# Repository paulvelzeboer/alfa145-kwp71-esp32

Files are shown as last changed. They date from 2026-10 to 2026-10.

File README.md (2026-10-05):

# Alfa 145 QV KWP71 reader: ESP32 CYD + ISO 9141 Click

Reads a **Bosch Motronic M2.10.4** (Alfa Romeo 145 QV, part 0261204478) over the K-line with the old Bosch **KWP71** protocol. It runs on an **ESP32-2432S028 "Cheap Yellow Display"** with a **MikroE ISO 9141 Click**, and shows a live dashboard on the CYD's screen: an rpm gauge, four values (battery, coolant, air temp, air quantity), the ECU ID numbers, and a boot splash with the car badge.

**Status (22 Sep 2026):** the full handshake and live values work on the real ECU (bench, engine off). The ESP32 reads 12.27 V, 18 °C and 0 rpm, plus the ID blocks: HW 0261204478, SW 1037357941, PN 46525168. The smoother dashboard (rpm polled ~3–4×/s, display on the second core) compiles but hasn't been tested on the ECU yet.

The full bring-up story, wiring, protocol findings and troubleshooting are in **[docs/kwp71-m2104-bringup.md](docs/kwp71-m2104-bringup.md)**.

## Repository layout

| Path | What |
| --- | --- |
| `firmware/kwp71_m2104_esp32/` | Main sketch: KWP71 handshake, polling, TFT dashboard, demo mode |
| `firmware/kline_loopback_test/` | Wiring test: sends bytes on TX (GPIO27) and checks they come back on RX (GPIO22) |
| `tools/kwp71_m2_10_4.py` | PC tool: KWP71 over a KKL / VAG-COM 409.1 cable (`--probe` for wakeup + sync only) |
| `tools/m2104_sim.py` | M2.10.4 simulator: the PC + KKL cable plays the ECU for desk testing |
| `tools/check_wakeup.py` | Decodes the 5-baud 0x10 wakeup from a sigrok CSV capture |
| `tools/make_case.py` | Generates the case (STL + 3MF) from the dimensions at the top of the file |
| `tools/trace_badge.py` | Traces a badge image into outlines for the lid |
| `tools/make_logo_header.py` | Converts a logo image into display data for the sketch |
| `docs/kwp71-m2104-bringup.md` | Documentation: bring-up plan, results, dashboard, troubleshooting |
| `captures/` | Logic analyzer captures (the existing ones show no K-line activity; see the doc, P0) |
| `hardware/` | Printable case for the CYD + Click: STL files plus `case_lid.3mf` for multi-colour printing, see [hardware/README.md](hardware/README.md) |
| `archive/` | Older sketch version and an old KKL tool log, for reference only |

## Hardware and wiring

| From | To | Note |
| --- | --- | --- |
| CYD CN1 IO27 (K_TX) | Click mikroBUS pin marked **RX** | the Click's pin names are from its own side, so TX/RX cross |
| Click mikroBUS pin marked **TX** | CYD CN1 IO22 (K_RX) | |
| CYD CN1 3.3V / GND | Click +3.3V / GND | Click jumper **JP1 = 3V3** (5V would put 5 V on GPIO22) |
| Click K screw | ECU diag connector **pin 3 (K)** | 3-pin Fiat/Alfa connector: pin 1 not connected, pin 2 GND, pin 3 K |
| Click GND | ECU diag connector **pin 2 (GND)** and 12 V minus | shared ground is required |
| 12 V (1 A fuse) | Click VS terminal + ECU supply | |

Never connect the K-line or 12 V directly to the ESP32 or the logic analyzer. For probing the K-line, use a 47 kΩ / 15 kΩ divider (see the doc).

## Firmware

Needs the ESP32 Arduino core (tested with 3.3.11) and **TFT_eSPI** (2.5.43) set up for the CYD pins with `ST7789_DRIVER`. The sketch itself switches on the backlight, turns off colour inversion and sets BGR colour order; the stock setup gets all three wrong for this panel.

```sh
arduino-cli compile --upload -p /dev/cu.usbserial-XXXX \
  --fqbn esp32:esp32:esp32:UploadSpeed=115200 firmware/kwp71_m2104_esp32
arduino-cli monitor -p /dev/cu.usbserial-XXXX -c baudrate=115200
```

The CYD's CH340 USB chip drops out at the default 921600 baud, hence `UploadSpeed=115200`.

`#define DEMO_MODE 1` shows simulated values without an ECU. Set it to `0` for the car.

The Alfa badge on the boot splash and in the status bar comes from an image that isn't in this repository, since car maker logos are trademarks. To show it, put your own `logo.png` in the project root and run:

```sh
pip install pillow
python3 tools/make_logo_header.py logo.png
```

Without that header the sketch still builds: the splash is then text-only.

## PC tools

```sh
pip install pyserial
python3 tools/kwp71_m2_10_4.py --port /dev/cu.usbserial-AH01164M --probe   # KKL: wakeup + sync only
python3 tools/m2104_sim.py --port /dev/cu.usbserial-AH01164M              # KKL plays the ECU
python3 tools/check_wakeup.py capture.csv --channel K_LINE --address 0x10 # check a wakeup capture
```

Only one tester may be on the K-line at a time: unplug the KKL when the Click is connected, and the other way round (the simulator setup excepted).

## Protocol facts for this ECU (measured)

| Item | Value |
| --- | --- |
| Wakeup | address 0x10 at 5 baud, K-line idle high ≥ 2 s before the start bit |
| Sync | ECU sends 0x55 about 180–190 ms after the stop bit, then `32 86 04 15 26` at 4800 baud |
| Keyword reply | complement of byte #1: 0x86 → **0x79** |
| Blocks | `LEN CTR TYPE DATA… 03`. **LEN counts the 0x03.** Every byte is echoed inverted, except the 0x03 |
| Quirk | the ECU always sends the LEN byte of its first block twice; echo the repeat, don't store it |
| Echo timing | 10–30 ms before each echo works; 0 ms is rejected |
| ID blocks | type F6, ASCII reversed: 0261204478 / 1037357941 / 46525168 |
| Battery | `01 01 00 36` → FE + 1 byte, × 0.1319 V (calibrated at 12.4 V) |
| Coolant | `08 03` → FB + 2 bytes, polynomial on the low byte |
| RPM | `01 02 00 3B` → FE + 2 bytes; formula **not verified** with a running engine |

## 3D-printed case

`hardware/` holds a two-part case: a shell with posts for the CYD and a slide-in holder for the Click, and a lid with a window for the display and the quadrifoglio inlaid in its top layers. Regenerate after changing any dimension:

```sh
python3 tools/make_case.py
```

Print `case_clickfit.stl` and `case_fitcheck.stl` first; they check the fit in minutes. Details and print settings are in [hardware/README.md](hardware/README.md).

## Open items

- RPM formula and a second battery calibration point, with the engine running.
- The first request after the handshake always gets a NAK. It's harmless, but a short pause might avoid it.
- Air temperature and air quantity have display cells but aren't requested from the ECU yet (air temp is probably ADC channel 02; the air quantity address is unknown).
- The case is unprinted apart from the Click holder coupon. The terminal height under the Click (7.0 mm) and the pin height above it (8.0 mm) are estimates, and they set the case height.

## License

MIT, see [LICENSE](LICENSE).

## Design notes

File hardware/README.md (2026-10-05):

# Case for the CYD + ISO 9141 Click

Two-part printable case, generated by [`tools/make_case.py`](../tools/make_case.py):

| File | What | Size |
| --- | --- | --- |
| `case_fitcheck.stl` | Coupon with the CYD post pattern. **Print this first.** | 122 × 56 × 7.8 mm |
| `case_clickfit.stl` | Coupon with the Click holder, at the real board height. **Print this too.** | 37 × 39 × 13.9 mm |
| `case_bottom.stl` | Shell: floor, walls with openings, CYD posts, Click slide-in holder | 127.2 × 60.8 × 21.1 mm |
| `case_lid.3mf` | **Lid + badge as one object in three parts**, badge inlaid flush - open this for multi-colour printing | 127.2 × 60.8 × 8 mm |
| `case_lid.stl` | Lid: screen window and lip, **no badge** - the base part if you prefer STLs | 127.2 × 60.8 × 8 mm |
| `case_lid_badge_triangle.stl` | Badge triangle, inlaid in the lid's top 0.6 mm | 44 × 39.8 × 0.6 mm |
| `case_lid_badge_clover.stl` | Clover, inlaid in the same 0.6 mm | 25.3 × 25.3 × 0.6 mm |
| `case_lid_embossed.stl` | Lid with the badge raised 1.4 mm, for printing in one colour | 127.2 × 60.8 × 9.4 mm |

Assembled height is about 23.1 mm.

> **The CYD outline and hole pattern come from the manufacturer drawing** ([mischianti.org](https://mischianti.org/wp-content/uploads/2025/04/ESP32-2432S028-Cheap-Yellow-Display-Dimensions.jpg.webp)): board 86.0 x 50.0 mm, hole centres 4.0 mm in from each edge, so the pattern is **78 x 42 mm**, corners R1.6.
>
> **Everything else is still nominal** and not measured: the mounting hole diameter (assumed 3.0 mm, not dimensioned in the drawing), the position of the active display area on the board, the Click's outline and the height of its screw terminals. Print the fit-check coupon first; nobody has printed any of this yet.

## Layout

```text
   top view of the open shell
   +---------------------------------------------+
   |  o                           o  |           |
   |        [   CYD board     ]      |  [Click]  ]==  screw terminals
   |  o                           o  |           |      (opening in the wall)
   +---------------------------------[wires]-----+
```

- **The Click's pins set the height.** The lid is closed over the Click, so the pins (`CLICK_PIN_H`, 8 mm, **measure this** - more if plugs stay on with the lid shut) are the tallest thing inside: 19.1 mm of inner height.
- **The CYD posts are 11.5 mm tall**, derived, not fixed: the generator makes them exactly tall enough to bring the display to 2 mm under the lid, so the screen isn't sunk in a well. Change any height and the posts follow.
- **The lid is flat** at this height. If a change ever makes the Click taller than the display, the generator sinks the screen panel automatically instead.
- **The lid has no screws.** It drops in with a 6 mm lip, 0.3 mm clearance per side. If it's loose, raise `LID_CLEAR`; if it's tight, lower it.
- **Posts** are hollow for M3 self-tapping screws: 2.4 mm pilot for the CYD, 2.2 mm for the Click. The four CYD posts carry a **2.7 mm alignment pin, 1.8 mm tall**, that enters the board's mounting hole, so the board sits in place even without screws. If the pins don't enter, measure the hole and set `CYD_HOLE_DIA`; the pin is that minus `SPIGOT_CLEAR` (0.3 mm).
- **The Click slides into a holder, pins up** - its mounting holes aren't used. From [`iso_9141_click_v101.dxf`](../iso_9141_click_v101.dxf): outline 25.40 × 28.57 mm, two 8-pin headers 22.86 mm apart (1.27 mm from the long edges), pins running from 3.81 to 21.59 mm along the board.
  - **A pocket at the back edge** takes the last 3 mm of the board, where there are no pins. Nothing grips the long edges: a rail there would ride over the pin rows while sliding in.
  - **Two ledges** support the front corners from below, clear of the screw terminals in the middle. Their ramped snap nubs sit on top of the board and clear both pin columns.
  - **The board sits `CLICK_BOARD_Z` = 8.5 mm above the floor**: `CLICK_TERM_STACK` (7.0 mm of terminal under the board) plus 1.5 mm of air. **Measure the terminal height and correct `CLICK_TERM_STACK`** - it is the only number that sets the board height, and 7.0 is an estimate from the first fit print.
  - **Fitting:** wire the terminals, slide the back edge 3 mm into the pocket, then press the front down until it snaps over the nubs. Do any wiring to the pins before closing the lid: the lid covers the Click completely.
- **A quadrifoglio is embossed on the lid**, right of the screen window, **41 × 37 mm** in two levels: the rounded triangle stands 0.6 mm proud and the clover 1.4 mm, so the clover reads clearly against it.
  - **It is traced from an image**, so the shape is the real badge rather than my approximation of it:
    ```sh
    pip install pillow
    python3 tools/trace_badge.py clover.png
    ```
    That writes `tools/badge_data.py`, which `make_case.py` picks up automatically. Green pixels and the outline around them become the clover; the remaining grey becomes the triangle, filled solid.
  - **The image and the traced data are not in the repository** (car maker logos are trademarks): `clover.png` and `tools/badge_data.py` are in `.gitignore`. Without them the generator falls back to a clover drawn from curves, so the STLs still build.
  - `CLOVER = False` removes the badge; `CLOVER_H` and `CLOVER_TRI_H` set the two relief heights.
  - **Printing it in green:** the clover is the only thing above 3.0 mm from the lid's underside, so a filament change at that layer gives a green clover on a grey triangle.
- **One opening only:** the Click's terminal wires, in the front wall (x 95.1-117.1, 2.5-10.5 mm above the floor). Every other wall is solid. The K-line and 12 V wires go to the Click's screw terminals, so they leave through that opening. There is no USB cut-out; set `USB_OPENING = True` to get one back, and no opening behind the CYD where its micro-SD slot sits.

## Printing the badge in other colours (Bambu Studio + AMS)

**Open `case_lid.3mf`.** It holds one object made of three parts, already in
place: `lid`, `badge triangle` and `badge clover`. Right-click a part and pick
its filament, for example white for the triangle and green for the clover. The
file carries suggested colours (grey / white / green), which some slicers show
straight away.

**The badge is inlaid, not raised:** all three parts end flush at the lid
surface (2.0 mm), with the colours filling the top 0.6 mm, so the lid stays
flat and the badge is a colour change only. The parts deliberately overlap each
other and the lid; slicers give an overlap to the part listed last, which is
why the clover comes after the triangle. `BADGE_INLAY = False` in the generator
raises the badge instead, and `BADGE_INLAY_DEPTH` sets how deep the colours
reach.

If you would rather build it from STLs: open `case_lid.stl`, then right-click
the object, **Add part -> Load**, and pick `case_lid_badge_triangle.stl` and
`case_lid_badge_clover.stl`. Loading as a part keeps each file's coordinates,
so they land exactly on the lid.

The parts meet rather than overlap: the lid ends at 2.0 mm, the triangle runs 2.0-2.6 mm, the clover 2.6-3.4 mm, and the clover sits entirely within the triangle's footprint. For a single-colour print use `case_lid_embossed.stl` instead: there the badge stands 1.4 mm proud, so it is visible without a colour change. The inlaid badge would be invisible in one colour.

## Printing

- **Material:** PLA or PETG. PETG if it's going to sit in a car in the sun.
- **Layers:** 0.2 mm, 3 perimeters, 20% infill.
- **Orientation:** both parts flat on the bed as generated, no supports needed. The lid prints with the screen panel upwards.
- **Time:** the coupon is a few minutes; the shell is roughly 2–3 hours depending on the printer.

## Checking the fit, then adjusting

1. Print `case_fitcheck.stl` (CYD posts) and `case_clickfit.stl` (Click holder). The CYD should drop onto the pins without force, and the Click should slide into the rails and click past the nubs.
2. Measure anything that's off and change the numbers in the `PARAMETERS` block at the top of `tools/make_case.py`:
   - `CYD_W/D/T`, `CYD_HOLE_INSET_X/Y`, `CYD_HOLE_DIA` for the display board (outline and insets now match the drawing; only the hole diameter is a guess),
   - `CLICK_W/D/T` (from the DXF), `CLICK_TERM_STACK` and `CLICK_BOARD_Z` for the space under the board, `CLICK_RAIL_*`, `CLICK_LEDGE_LEN`, `CLICK_NUB_H` for the holder,
   - `CYD_SCREEN_W/D` and `CYD_SCREEN_OFF_X/Y` for the window over the display,
   - `CLICK_PIN_H` for the pin height (it sets the whole case height), `POST_H_MIN` for the minimum space under the CYD,
   - `WALL`, `FLOOR`, `GAP`, `GAP_Y`, `LID_CLEAR` for the case itself.
3. Regenerate: `python3 tools/make_case.py`

The window is `SCREEN_MARGIN` (1.2 mm) larger than the active display area. If the bezel peeks out, raise it; if the window covers pixels, lower it or shift the screen with `CYD_SCREEN_OFF_X/Y`.

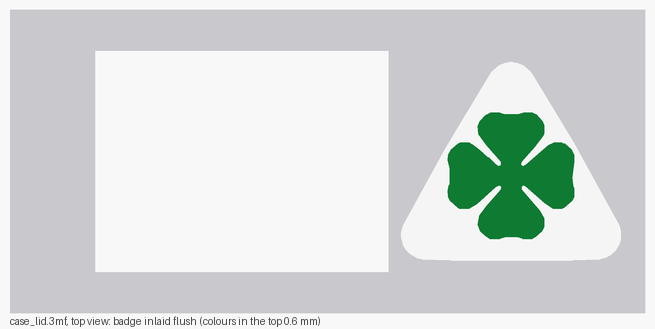
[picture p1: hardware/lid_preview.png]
Lid, top view


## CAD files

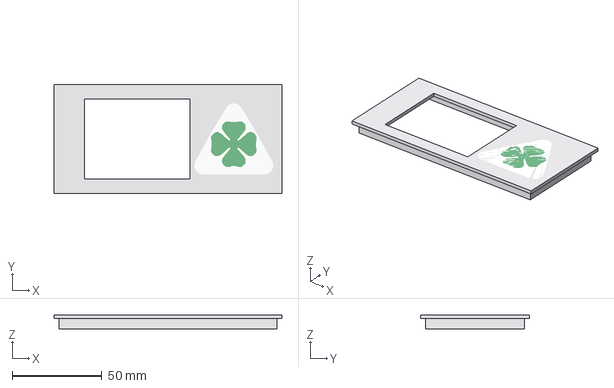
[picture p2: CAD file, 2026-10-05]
hardware/case_lid.3mf
127.2 x 60.8 x 8.00 mm

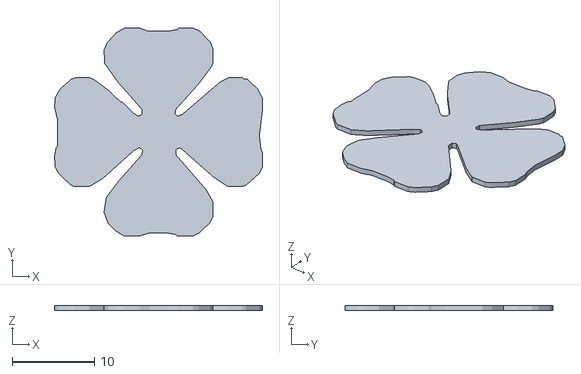
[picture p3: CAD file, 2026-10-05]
hardware/case_lid_badge_clover.stl
25.3 x 25.3 x 0.6

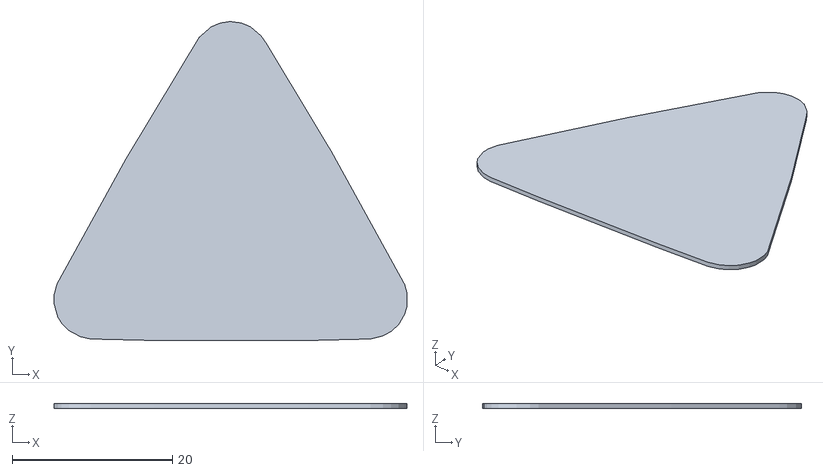
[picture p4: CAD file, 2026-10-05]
hardware/case_lid_badge_triangle.stl
44.0 x 39.8 x 0.6

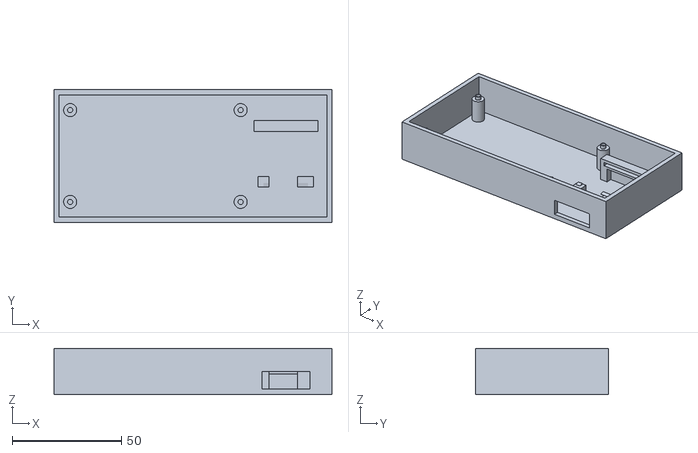
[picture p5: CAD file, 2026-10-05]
hardware/case_bottom.stl
127.2 x 60.8 x 21.1

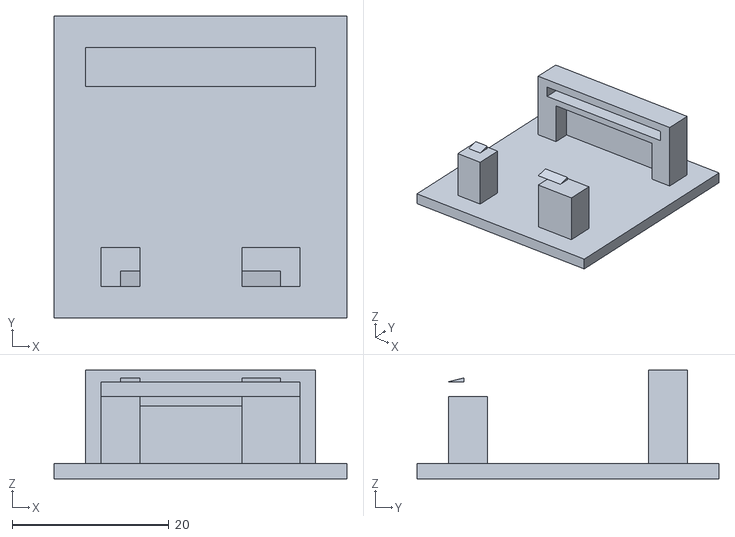
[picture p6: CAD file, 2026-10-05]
hardware/case_clickfit.stl
37.4 x 38.6 x 13.9

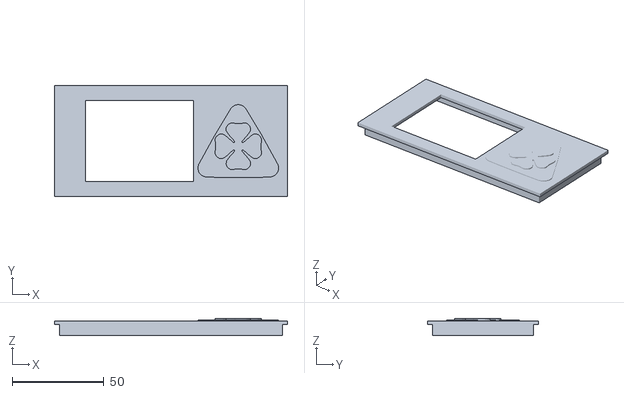
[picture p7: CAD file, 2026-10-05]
hardware/case_lid_embossed.stl
127.2 x 60.8 x 9.40

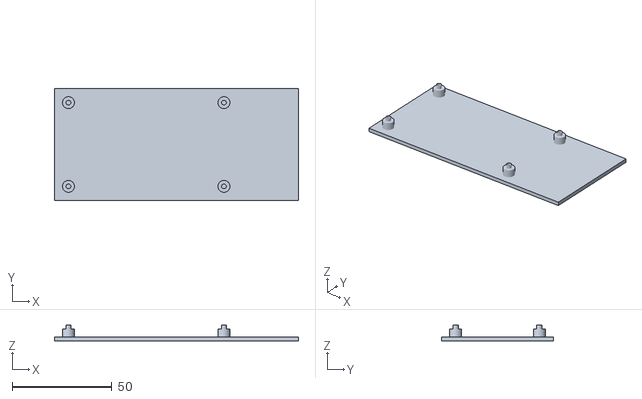
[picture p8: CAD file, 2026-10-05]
hardware/case_fitcheck.stl
122.4 x 56.0 x 7.80

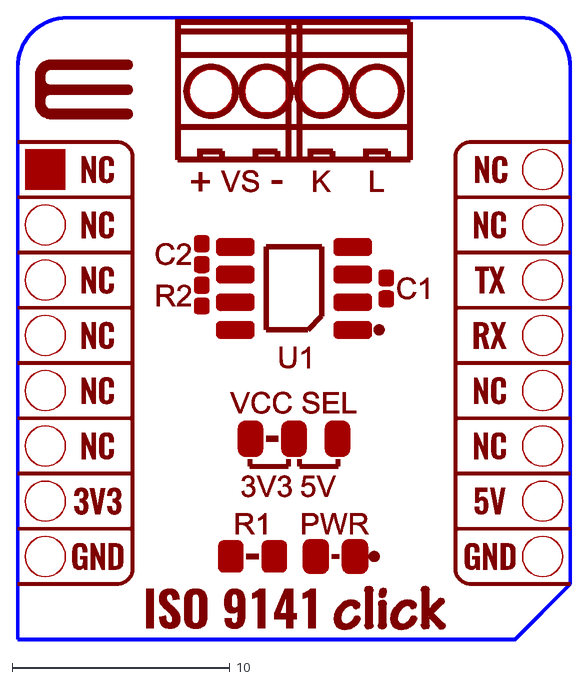
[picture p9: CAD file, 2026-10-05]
iso_9141_click_v101.dxf
25.6 x 28.7

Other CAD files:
hardware/case_lid.stl

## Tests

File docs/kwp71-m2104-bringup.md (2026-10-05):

# ESP32 CYD → ISO 9141 Click → Bosch M2.10.4: KWP71 bring-up plan

Sep 21, 2026 · @Paul

## Goal and starting point

The fastest route to a working ESP32 link is to copy the handshake that already works. First record the KKL cable's session on the K-line with the logic analyzer. Then make the ESP32's K-line trace match it, phase by phase.

| Path | Status | Evidence |
| --- | --- | --- |
| MacBook M4 → KKL / VAG-COM 409.1 (FTDI, `/dev/cu.usbserial-AH01164M`) → 3-pin Fiat/Alfa diag → M2.10.4 | Works | `kwp71_m2_10_4.py`: address 0x10, 4800 baud, 0x55 about 180 ms after the stop bit, then `32 86 04 15 26`, reply 0x79, info block = part number 0261204478. Confirmed again with `--probe` on 22 Sep 2026 |
| ESP32-2432S028 → MikroE ISO 9141 Click → K-line → M2.10.4 | **Works** on the real ECU: full handshake, ID blocks and live values (22 Sep 2026) | K on connector pin 3 plus shared ground on pin 2, 20 ms echo delay, LEN counts the 0x03, the ECU's repeated LEN byte handled. Reads 12.27 V, 18.0 °C and 0 rpm (engine off) |

The plan works outward from the ESP32 pin, and each phase has a pass check:

1. The ESP32 pin sends the correct 0x10 wakeup.
2. The Click reproduces that wakeup on the K-line.
3. The ECU answers with 0x55.
4. The ESP32 decodes the answer and replies 0x79.
5. The info blocks arrive.

If a check fails, the cause is in the one link that was added last.

```mermaid
flowchart LR
  A[P0 Golden capture<br/>KKL + analyzer] --> B[P1 ESP32 pin<br/>no Click]
  B --> C[P2 Click on bench<br/>12 V, no ECU]
  C --> S[P2b Full session<br/>vs simulator]
  S --> D[P3 Wakeup to ECU<br/>expect 0x55]
  D --> E[P4 Keyword reply<br/>0x79]
  E --> F[P5 Info blocks<br/>+ keep-alive]
```

Each box is one phase in the step-by-step plan below. Don't start a phase until the one before it passes its check.

## Parts and known protocol parameters

Everything the ESP32 has to reproduce is already proven by `kwp71_m2_10_4.py` against this ECU. Copy these values; don't guess new ones.

| Part | Role | Notes |
| --- | --- | --- |
| [ESP32-2432S028 "CYD"](https://github.com/witnessmenow/ESP32-Cheap-Yellow-Display/blob/main/PINS.md) | Tester MCU | Use connector CN1 (GND, IO22, IO27, 3.3V). UART2 on TX=GPIO27, RX=GPIO22. USB (UART0) stays free for logs. |
| [MikroE ISO 9141 Click](https://www.mikroe.com/iso-9141-click) (MIKROE-4331) | K-line transceiver, [L9637D](https://download.mikroe.com/documents/add-on-boards/click/iso_9141_click/iso-9141-click-schematic-v101.pdf) | JP1 selects logic level, and it **must be 3V3**. Has a 4.7 kΩ K-line pull-up to VS. The VS terminal takes 4.5–36 V. The L-line input is not needed. |
| USB logic analyzer (FX2 / "Saleae Logic" clone, sigrok `fx2lafw`) | Debugging | Pins CH1–CH8 (sigrok D0–D7), GND and CLK. Logic inputs only. It must never see 12 V directly. |
| Resistors 47 kΩ + 15 kΩ | K-line probe divider | Scales 14.4 V down to 3.5 V for analyzer CH3 |
| 12 V supply with 1 A inline fuse | ECU + Click VS | Use the same supply or battery that powered the ECU during the KKL tests |
| KKL / VAG-COM 409.1 + 3-pin Fiat/Alfa adapter | Golden reference only | Disconnect it before the Click touches the K-line |
| Bosch M2.10.4 (0261204478) | Target |  |

| Parameter | Proven value | Source |
| --- | --- | --- |
| Idle before wakeup | K-line high ≥ 2 s | script phase 1 |
| Wakeup address | 0x10, 5 baud, 8N1, LSB first, 200 ms/bit (start bit + 8 data + stop bit = 2.0 s) | `--address` default |
| Link speed after wakeup | 4800 baud 8N1 | `--baud` default, confirmed working |
| Sync | ECU sends 0x55 about **180 ms** after the stop bit (187 ms measured on the Mac, including up to \~16 ms of USB delay) | `--probe`, 22 Sep 2026 |
| Keyword | After 0x55 the ECU sends `32 86 04 15 26`. The tools read at most 5 bytes, so more may follow. Byte #1 = **0x86** | `--probe`, 22 Sep 2026 |
| Keyword reply | Complement of the keyword byte = **0x79** | `output.txt` |
| Reply delay | Both tools read up to 5 bytes after 0x55 (stopping early after a 150 ms gap), then wait 8 ms and send. This ECU sends exactly 5, so the reply goes out about 9 ms after the 5th byte | `--byte-timeout 0.15`, `--turnaround-ms 8`. Measure the real gap in the P0 capture |
| Block format | `LEN CTR TYPE DATA… 03`. **LEN counts the 0x03**: block 1 = `0D` → `01 F6` + 10 characters + `03`. The ECU always sends the LEN byte of its first block **twice**, because it doesn't accept the first echo. A 0x03 before the end is data | ESP32 raw trace, 22 Sep 2026. The old "LEN excludes 0x03" note was an illusion caused by the repeated byte |
| Lock-step echo | The receiver echoes every byte inverted, except the final 0x03. The ESP32 waits **20 ms** before each echo and before each byte it sends. At 0 ms the ECU rejects the echo; 10–30 ms all work | `send_block()` / `read_block()` |
| Self-echo | The transceiver's RX mirrors the K-line, so you receive every byte you send. Read it back and discard it | `write_byte_sync()`. The L9637D behaves the same as the KKL |
| ID blocks (3) | Type F6, ASCII reversed: `8744021620` = **0261204478** (Bosch hardware no.), `1497537301` = **1037357941** (Bosch software no.), `86152564` + `FF FF` = **46525168** (Alfa/Fiat part no.) | ESP32 on the real ECU, 22 Sep 2026 |
| Keep-alive | NOP / ACK block, type 0x09. The two sides strictly take turns: the ECU answers every tester block with exactly one block, the NOP included. Read that reply before sending again | `REQ["nop"]` |

## Wire diagram

Four signal wires, one K-line wire, and one ground star point. The Click's mikroBUS TX and RX are named from the Click's own side, so they cross over: **ESP32 GPIO27 goes to the Click's RX pin, and the Click's TX pin goes to GPIO22.** This matches the [schematic v101](https://download.mikroe.com/documents/add-on-boards/click/iso_9141_click/iso-9141-click-schematic-v101.pdf): L9637 pin 4 (TX) connects to mikroBUS RX, and pin 1 (RX) connects to mikroBUS TX.

```mermaid
flowchart LR
  MAC[MacBook M4<br/>USB] -->|USB-C: power + logs| CYD
  MAC -->|USB| LA
  CYD[ESP32-2432S028<br/>CN1] -->|IO27 = K_TX| CRX[Click pin marked RX<br/>= L9637 TX input]
  CTX[Click pin marked TX<br/>= L9637 RX output] -->|K_RX = IO22| CYD
  CYD -->|CN1 3.3V + GND| CPWR[Click pins<br/>+3.3V and GND]
  CRX --- CLK[ISO 9141 Click<br/>JP1 = 3V3]
  CTX --- CLK
  CPWR --- CLK
  CLK -->|K terminal| KL((K-line))
  KL --> ECU[M2.10.4<br/>diag K pin]
  PSU[12 V supply<br/>1 A fuse] -->|VS terminal| CLK
  PSU -->|+12 V, ign.| ECU
  KL --> DIV[Divider<br/>47k over 15k]
  DIV -->|CH3 = K_LINE| LA[Logic analyzer<br/>CH1-CH8, GND, CLK]
  CYD -.->|CH1 = IO27, CH2 = IO22| LA
  GND{{Ground star<br/>ECU GND}} --- CLK
  GND ---|analyzer GND| LA
```

Solid arrows show signal or power flow; the dotted arrow shows the analyzer probes on CN1. Every GND (ESP32 CN1, Click mikroBUS GND, Click VS−, ECU ground, 12 V supply −, divider bottom, analyzer GND) joins at the ground star.

**Logic analyzer pins.** The labels CH1–CH8 correspond to sigrok's names D0–D7, so the sigrok commands in this doc still say `-C D0=…`.

| Analyzer pin | sigrok name | Label in captures | Connect to |
| --- | --- | --- | --- |
| CH1 | D0 | K\_TX | CYD CN1 IO27 |
| CH2 | D1 | K\_RX | CYD CN1 IO22 |
| CH3 | D2 | K\_LINE | Divider node (47 kΩ / 15 kΩ), **never the K-line itself** |
| CH4–CH8 | D3–D7 |  | Leave unconnected |
| GND |  |  | Ground star (ECU GND) |
| CLK |  |  | Leave unconnected. It's an external clock input; sigrok samples on its own clock |

Check the mapping once: connect only CH1 to GND and run `sigrok-cli -d fx2lafw --samples 8 -O bits`. D0 should read all 0s, and the unconnected channels read 1s.

| From | Pin | To | Pin | Wire | Notes |
| --- | --- | --- | --- | --- | --- |
| CYD CN1 | IO27 | Click mikroBUS | **RX** | K\_TX | Crossover. Also probe it with analyzer CH1 |
| Click mikroBUS | **TX** | CYD CN1 | IO22 | K\_RX | Crossover. Also probe it with analyzer CH2 |
| CYD CN1 | 3.3V | Click mikroBUS | +3.3V | Logic supply | Only works with JP1 set to 3V3 |
| CYD CN1 | GND | Click mikroBUS | GND | Ground |  |
| Click | K-L terminal, **K** screw | ECU diag | K-line pin | K-line | Leave the L screw empty. Check which screw is K on the silkscreen |
| 12 V supply + (fused) |  | Click | VS terminal, VS | VS | 4.5–36 V |
| 12 V supply − |  | Click | VS terminal, GND | Ground | Also goes to the ECU ground |
| K-line |  | 47 kΩ → node → 15 kΩ → GND |  | Probe divider | Divider node goes to analyzer CH3 |
| Analyzer | CH1 / CH2 / CH3 / GND (CLK unused) | IO27 / IO22 / divider / ground star |  | Probes | sigrok D0 / D1 / D2, labelled K\_TX / K\_RX / K\_LINE |

**Finding the ECU's K pin:** use the same 3-pin Fiat/Alfa adapter the KKL worked through. On its OBD-16 side, K is pin 7, GND is pins 4 and 5, and +12 V is pin 16. Check with a multimeter which of the 3 pins connects to OBD pin 7. Tap the K-line, GND and +12 V there, for example with an OBD-16 breakout. That uses the path already proven with the KKL.

**3-pin Fiat/Alfa diagnostic connector on this ECU:** pin 1 has no wire to the ECU, pin 2 = **GND**, pin 3 = **K**. There's no L-line. Connect the Click's K screw to **pin 3**, and connect the Click's GND to **pin 2** as well as to the 12 V supply's minus. Without that shared ground the ECU doesn't respond.

## Safety and signal levels

The ESP32 and the analyzer run at 3.3 V logic; the K-line swings to about 12–14.4 V. One wrong wire can kill a GPIO or an analyzer channel, so check these before every power-up.

- [ ] **JP1 on the Click is set to 3V3.** At 5V the Click's RX output idles at 5 V, and GPIO22 is not 5 V tolerant.
- [ ] **Measure the Click's TX pin** (the wire going to GPIO22) with the Click powered but the ESP32 not yet connected. It should idle at about 3.3 V; if it reads higher, stop.
- [ ] **Never connect the K-line, VS or +12 V directly to the ESP32 or the analyzer.** Analyzer CH3 only connects to the divider node.
- [ ] **Check the divider:** 47 kΩ top, 15 kΩ bottom gives 14.4 V → 3.48 V and 12 V → 2.90 V. It reads as logic 1 above the 2.0 V threshold. A K-line low of ≤ 1 V reads as ≤ 0.25 V, logic 0.
- [ ] **One ground.** ESP32, Click, analyzer, 12 V supply and ECU all connect to the ECU ground. The Mac powers both the ESP32 and the analyzer, so its USB ground is already common with them.
- [ ] **Only one tester on the K-line.** Unplug the KKL before connecting the Click. Two pull-ups and two drivers corrupt every byte.
- [ ] **Fuse the 12 V feed at 1 A** and check VS polarity before closing the circuit.
- [ ] **Connect with the power off.** Make all connections with 12 V off, then power up in this order: 12 V, then the ESP32 over USB.

## Step-by-step bring-up

Seven phases, each ending in a pass check you can see on the analyzer. Capture at 100 kHz and save as `.sr`, then decode offline. Long captures sometimes stall on this Mac with `LIBUSB_ERROR_PIPE`. If one hangs, Ctrl-C and run it again.

### P0: Record the golden handshake with the KKL (about 20 min)

This records what "working" looks like on the wire. You'll compare every later phase against it.

1. Wire it the way that already works: KKL → 3-pin adapter → ECU, powered. Add only the divider on the K-line, with analyzer CH3 on the divider node and analyzer GND on ECU ground.
2. Start the capture, then the script, in one line:

```
sigrok-cli -d fx2lafw --config samplerate=100k --samples 1000000 -C D2=K_LINE -o golden.sr & sleep 0.5; python3 tools/kwp71_m2_10_4.py --port /dev/cu.usbserial-AH01164M; wait
```

3. Check the wakeup and decode the bytes:

```
sigrok-cli -i golden.sr -O csv:header=true:dedup=true:label=channel:time=true -o golden.csv
python3 tools/check_wakeup.py golden.csv --channel K_LINE --address 0x10
sigrok-cli -i golden.sr -P uart:rx=K_LINE:baudrate=4800 -A uart=rx-data --protocol-decoder-samplenum > golden_bytes.txt
```

4. In `golden_bytes.txt`, each sample number ÷ 100 = ms. Write down these five gaps:
   - W1: end of the wakeup stop bit → 0x55
   - KW1 → KW2 (0x86)
   - **W4: end of KW2 → start of 0x79** (the most important number)
   - 0x79 → the first ECU block's LEN byte
   - End of an ECU byte → start of the tester's inverted echo

**Pass:** `check_wakeup.py` prints `RESULT: OK - decoded 0x10`, and the decoded stream shows `55`, `86`, `79` and a first block containing ASCII digits.

**Fixed in `kwp71_m2_10_4.py` on 22 Sep 2026:** the tool used to clear its input 190 ms after the stop bit. This ECU's 0x55 arrives at about 187 ms, so it was thrown away, and `--probe` reported `never received 0x55` while the ECU was actually answering (it logged only `32 86 04`). The tool now listens from the end of the stop bit. It also waits for 0x55 by time, skipping stray bytes, instead of reading only 3 bytes.

### Firmware for P1–P5: `kwp71_m2104_esp32.ino`

Every ESP32 phase runs the same sketch unchanged. It's a port of the working Python script and repeats this cycle until it connects:

1. Hold the line idle high for 2 s.
2. Send the 0x10 wakeup on GPIO27, which takes 2.0 s.
3. Wait for 0x55, up to 3 × 800 ms.
4. Wait 1 s, then start again.

Follow it on the Serial Monitor at 115200 baud; the TFT shows the same log with less detail. These are the settings you may tune:

| Constant | Value | Controls |
| --- | --- | --- |
| `IDLE_BEFORE_MS` | 2000 | Idle-high time before the start bit |
| `BIT_MS` | 200 | 5-baud bit time |
| `N_SYNC`, `BYTE_TIMEOUT_MS` | 5, 150 | Reads up to 5 bytes after 0x55 and stops after a 150 ms gap. This ECU sends exactly 5 (`32 86 04 15 26`), so the reply goes out right after the 5th |
| `KW_POS` | 1 | Which byte after 0x55 is complemented (0x86 → 0x79) |
| `TURNAROUND_MS` | 8 | Delay before the keyword reply 0x79 (accepted by the ECU) |
| `ECHO_DELAY_MS` | 10 | Delay before every echo and every byte sent in a block exchange. Changed from 20 to 10 ms for faster rpm updates. 10 ms worked in the sweep, but hasn't been through a full session yet; go back to 20 if echoes get rejected |
| `ECU_LEN_INCLUDES_EOB` | 1 | LEN counts the 0x03 (confirmed on the real ECU) |
| `MAX_LEN_REPEATS` | 3 | How often the ECU may re-send a block's LEN byte (it always does once, for block 1) |
| `SELF_ECHO_TIMEOUT_MS` | 50 | How long to wait for our own byte to loop back through the L9637 |
| DEMO\_MODE | 0 | 1 = simulated dashboard values, no K-line traffic (see Dashboard) |

**How to capture a clean cycle:** start sigrok, then press the CYD's RST button within about 0.5 s. After a reset the start bit comes about 3 s in, so a 9 s capture holds one whole attempt. The first falling edge will be the real start bit, which is what `check_wakeup.py` needs.

### P1: ESP32 pin only (no Click, no 12 V)

1. Flash `kwp71_m2104_esp32.ino`. Connect analyzer CH1 to CN1 IO27 and analyzer GND to CN1 GND. Nothing else is connected.
2. Capture, pressing RST right after the command starts, then check:

```
sigrok-cli -d fx2lafw --config samplerate=100k --samples 900000 -C D0=K_TX -o p1.csv -O csv:header=true:dedup=true:label=channel:time=true
python3 tools/check_wakeup.py p1.csv --channel K_TX --address 0x10
```

**Pass:** `RESULT: OK - decoded 0x10`. The start bit comes after ≥ 2 s of high, and the frame is about 2.0 s long. The Serial log is expected to show `RX transitions …: 0` and `FAIL: no 0x55 sync byte` here, because nothing is connected to GPIO22.

### P2: Click on the bench, 12 V on, ECU not connected

1. Set JP1 to 3V3 and work through the safety checklist. Wire the ESP32 to the Click as in the wire table. Connect VS to the fused 12 V, and connect the divider to the Click's K screw only.
2. Probe CH1 = IO27, CH2 = IO22, CH3 = divider node.
3. Capture 900000 samples with `-C D0=K_TX,D1=K_RX,D2=K_LINE` (press RST), then run `check_wakeup.py` once for each channel.

**Pass:**

- All three channels decode 0x10. K\_LINE is the 12 V copy of the wakeup; K\_RX mirrors it.
- The Serial log shows `RX transitions seen during our own TX pulse: 3`. Anything else means the wakeup isn't getting from the K-line back to GPIO22.
- K\_LINE idles high between attempts, held up by the Click's 4.7 kΩ pull-up.

### P2b: Full session against the simulator (no ECU)

`m2104_sim.py` makes the MacBook and the KKL cable act as the M2.10.4. With it the whole firmware (wakeup, keyword, info blocks and polling) runs at your desk and can be repeated as often as you like, before the ECU is involved.

| Connect | To |
| --- | --- |
| Click K screw | KKL OBD pin 7 (K) |
| Fused 12 V | Click VS **and** KKL OBD pin 16 (the KKL needs 12 V to work) |
| GND | Click GND **and** KKL OBD pins 4 + 5 |

Keep the divider and CH1–CH3 as in P2. **Never have the real ECU on the same K-line.**

1. Start the simulator: `python3 tools/m2104_sim.py --port /dev/cu.usbserial-AH01164M`
2. Press RST on the CYD and watch both logs.

**Pass:**

- The simulator log shows `wakeup: … -> OK`, then `<- 79 keyword reply … -> OK`, the blocks `[info 1]`, `[info 2]` and `[final]`, then `== session up - answering requests ==`, followed by a steady flow of `RAM` / `ADC` answers.
- The ESP32 log shows `== HANDSHAKE COMPLETE ==` and `Batt:` lines, with no `Session lost`.

**Result on 22 Sep 2026:** passed. There were 35 poll cycles in 45 s (about 1.1 s each) with no `Session lost`, self-echo errors or echo errors. The keyword reply went out 160 ms after the keyword byte.

This run found one bug, now fixed. The sketch sent its NOP keep-alive but never read the ECU's reply block, so the next battery request collided with that reply. The log showed `self-echo 0x2 != sent 0x6`, and the session dropped after every first poll cycle.

The displayed values (`Batt: 0.21V RPM: 51 Cool: 140.4C`) are wrong with the simulator. The decode formulas read byte positions where the simulator's placeholder answers have the 0x03 end marker. A P0 capture of the real ECU will show whether the formulas or the placeholders are wrong.

**What the simulator can and can't tell you:**

- **Real values:** 0x10, 4800 baud, 0x55 after \~190 ms followed by 32 86 04 15 26 (keyword 0x86 → reply 79), all three ID blocks, the real battery/rpm/coolant answers, LEN counting the 0x03, and the ECU's two quirks (LEN of the first block sent twice, NAK for the first request).
- **Placeholders:** the gaps between the bytes after 0x55, every other delay, the block type bytes, info block 2, and the data answers.
- **Timing:** USB adds up to about 16 ms per read. A pass shows the firmware's logic is right; the real ECU remains the final test.
- **Expected note:** `note: tester LEN 03, this ECU profile would use 02` is normal. The sketch's `sendBlock()` counts the 0x03 in LEN, and the real ECU accepted that from the Python tool.

Once P0 gives you a real capture, copy the ECU's bytes and delays into a profile:

1. `python3 tools/m2104_sim.py --dump-profile > m2104.json`
2. Edit `m2104.json`.
3. Run with `--profile m2104.json`.

The simulator then replays your ECU instead of the placeholders.

### P3: Connect the ECU and expect 0x55

1. Turn 12 V off. Unplug the KKL. Connect the Click's K screw to the ECU's K pin, and join all grounds. Keep the divider on the K-line.
2. Turn 12 V and ignition on and wait 3 s. Start a capture of all three channels, then press RST.
3. Decode both lines:
   - `sigrok-cli -i p3.sr -P uart:rx=K_LINE:baudrate=4800 -A uart=rx-data --protocol-decoder-samplenum`
   - the same for K\_RX

**Pass:** 0x55 appears on K\_LINE and K\_RX, with a W1 close to P0. The Serial log no longer shows `FAIL: no 0x55`. The sketch's UART starts listening at the beginning of the stop bit, so it can't miss an early 0x55.

**Result on 22 Sep 2026: the first attempts failed, as below. Passed after moving K to pin 3 and adding the shared ground (see P3a).**

1. **Wrong pin first.** With the Click's K wire on the wrong ECU pin, the line was stuck low: `K-line idle level before wakeup: LOW` and `RX transitions: 0`. Taking the wire off the ECU brought back `HIGH` and 3, which proved the ECU side was pulling it low.
2. **Right pin, ECU on.** The line idles high and the wakeup goes out (`RX transitions: 3`), but the ECU sends nothing back: `nothing received at all` on every attempt.
3. **Same pin with the KKL** (Click's K wire removed): `kwp71_m2_10_4.py --probe` gets 0x55 after 187 ms, then `32 86 04 15 26`. So the ECU, its power and this pin are fine.

The KKL wakes the ECU and the Click doesn't. The most likely reason is the L-line: many KKL cables drive OBD pin 15 (L) together with K, and the Click can only receive on L, not drive it.

### P3a: Find out what wakes the ECU

There's one open question: what does the KKL do that wakes the ECU, which the Click doesn't? Two multimeter checks and one wiring test should answer it.

**Test 1: Map the 3-pin adapter** (multimeter on continuity, everything powered off). Check each of the adapter's 3 pins against its OBD socket. Also note which of the 3 pins the Click's K wire was on in P3.

| 3-pin adapter pin | → OBD 7 (K)? | → OBD 15 (L)? | → OBD 16 (+12 V) / 4, 5 (GND)? |
| --- | --- | --- | --- |
| Pin 1 |  |  |  |
| Pin 2 |  |  |  |
| Pin 3 |  |  |  |

**Test 2: Check the KKL cable** (cable unplugged). On its OBD plug, measure between pin 7 and pin 15.

- **About 0 Ω:** the cable ties K and L together, so its wakeup goes out on both lines.
- **Open:** it drives K only.

| Result | Meaning | Next |
| --- | --- | --- |
| An adapter pin goes to OBD 15, and the KKL connects 7 and 15 | The ECU most likely listens for the wakeup on **L** | Test 3 |
| No adapter pin goes to OBD 15 | L isn't the reason | If the Click was on the pin that goes to OBD 7, capture with the analyzer (below) |
| The Click was on a different pin than the one going to OBD 7 | Wrong pin | Move the Click's K wire to that pin and let the ESP32 retry |

**Test 3: Bridge L to K** (only if Test 1 finds an L pin):

1. Unplug the KKL.
2. Connect the Click's K wire to the adapter's K pin, and put a jumper wire from the L pin to the K pin. That copies what the KKL cable does internally.
3. Turn on the ECU and watch the ESP32 log. The ESP32 retries by itself about every 7 s.

**Pass:** `0x55 SYNC received`, then `Keyword[1]=0x86 -> reply 0x79`, then `== HANDSHAKE COMPLETE ==`.

**If Tests 1 and 2 don't settle it:** capture the KKL waking the ECU with the logic analyzer.

- **Probes:** CH3 through the divider on the K pin, and CH4 through a **second** 47 kΩ / 15 kΩ divider on the adapter's other signal pin.
- **What it shows:** which line carries the wakeup, and which one the ECU answers on.
- **What else it gives you:** the golden capture from P0, including whether the ECU sends more than 5 bytes after 0x55.

**Result of P3a (22 Sep 2026):** Test 1 answered it. There's **no L-line**: connector pin 1 has no wire to the ECU, pin 2 is GND and pin 3 is K. The earlier symptoms fit the Click's K wire being on pin 2 at first (line stuck low), then on pin 1 (idle high, no answer). With K on **pin 3** and the Click's GND on **pin 2**, the ECU answers the ESP32: 0x55 at 192 ms after the stop bit, then `32 86 04 15 26`.

### P4: Keyword reply

**Pass:** the Serial log shows:

```
0x55 SYNC received
Bytes after 0x55: xx 86
Keyword[1]=0x86 -> reply 0x79
Handshake OK - addr 0x10
```

There's no `WARN: no clean self-echo of the reply` message. K\_LINE shows `55 xx 86 79`. Compare the 86→79 gap with W4 from P0. If it differs by more than a few ms, adjust `BYTE_TIMEOUT_MS` (the main part of the gap) and `TURNAROUND_MS`.

**Result on 22 Sep 2026: passed.** The ESP32's raw trace shows 0x55 at 192 ms after the stop bit, then `32 86 04 15 26` at 10 ms intervals. Our 0x79 went out 7.4 ms after the 5th byte, and the ECU accepted it: its first block followed about 100 ms later.
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

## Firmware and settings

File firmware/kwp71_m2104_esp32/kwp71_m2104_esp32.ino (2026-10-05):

/*
 * KWP71 reader for Alfa 145 QV (Bosch Motronic M2.10.4, part 0261204478)
 * Hardware: ESP32-2432S028 (CYD) + ISO9141 click board
 *
 * Ported 1:1 from a CONFIRMED FULLY WORKING Python/pyserial tool
 * (kwp71_m2_10_4_fixed.py) that completed the ENTIRE KWP71 init sequence
 * over a KKL/VAG-COM 409.1 cable, including both ECU info blocks and the
 * final session block, then reached a live command REPL:
 *
 *   address 0x10, 4800 baud, break-style 5-baud wakeup (200ms/bit),
 *   n_sync=5 bytes read after 0x55, keyword byte = index 1 (0-based),
 *   turnaround 8ms before replying with the complement of the keyword byte.
 *   Confirmed result: keyword 0x86 -> reply 0x79, ECU accepted it.
 *   Info block 1 payload decoded (ASCII reversed) = "0261204478", the
 *   ECU's own Bosch part number - definitive proof of correct comms.
 *
 * Two real protocol bugs were found and fixed on the Python side, both
 * ported here:
 *   1) LEN/EOB: CORRECTED 22 Sep 2026 from a raw trace of the ESP32 on the
 *      real ECU. LEN counts COUNTER+TYPE+DATA+EOB (standard convention):
 *      block 1 = 0D | 01 F6 "8744021620" 03 (13), block 2 = 04 | 02 0A 01 03.
 *      The earlier "EOB arrives one byte past LEN" finding was an artifact:
 *      the ECU always sends the LEN byte of its first block TWICE (it doesn't
 *      accept the tester's first echo), and the repeat was read as data.
 *      readBlock() now echoes such a repeat without storing it, uses LEN to
 *      find the EOB (a 0x03 before that point is data, e.g. a counter of
 *      0x03), and falls back to scanning for 0x03 up to LEN + BLOCK_SLACK.
 *   2) Self-echo drift bug: since K-line is single-wire, every byte WE
 *      transmit loops back into our own RX and must be discarded before
 *      being treated as ECU data. The old approach deferred/counted this
 *      discard separately from the write, and the count drifted out of
 *      sync across multiple blocks, eventually causing real ECU bytes to be
 *      misidentified and discarded as leftover echo. Fix: kWriteByteSync()
 *      writes a byte and immediately consumes its own physical loopback
 *      echo right there, every time, with no separate counter/state to drift.
 *
 * Also: KWP71 requires continuous bus traffic roughly every 200-300ms or
 * the ECU silently times out and drops the session (looks like a dead bus
 * afterward - zero echo on anything sent). The main loop's parameter-poll
 * exchanges (pollAndDisplayParams(), back to back) satisfy this while
 * connected, so no extra keep-alive task is needed on the ESP32 side.
 *
 * Wiring (mikroBUS pins are named from the click's side, so they CROSS):
 *   GPIO27 (K_TX_PIN) -> click mikroBUS pin labelled "RX" (L9637 TX input)
 *   GPIO22 (K_RX_PIN) <- click mikroBUS pin labelled "TX" (L9637 RX output)
 *   CYD CN1 3.3V/GND  -> click +3.3V/GND, click JP1 set to 3V3 (NOT 5V)
 *   Click K-line -> car diagnostic connector K-line (3-pin Fiat/Alfa: pin K)
 *   Click VS/VBB -> +12V ignition-switched
 *   Click GND    -> chassis ground
 *
 * Needs TFT_eSPI configured for the CYD (ILI9341 240x320).
 */

#include <TFT_eSPI.h>
// Badge bitmaps: optional. Generate logo_data.h from your own image with
//   python3 tools/make_logo_header.py logo.png
// It is not in the repository (car maker logos are trademarks). Without it
// the splash is text-only and the status bar has no badge.
#if defined(__has_include)
#  if __has_include("logo_data.h")
#    include "logo_data.h"
#    define HAVE_LOGO 1
#  endif
#endif
#include "driver/uart.h"
#include "driver/gpio.h"

TFT_eSPI tft = TFT_eSPI();

// ---------- PROTOCOL CONSTANTS (from the confirmed-working Python defaults) ----------
#define K_TX_PIN 27
#define K_RX_PIN 22
#define TFT_BACKLIGHT_PIN 21   // CYD display backlight, active high

// DEMO_MODE 1: no K-line traffic at all - the dashboard shows simulated
// values (rpm sweeping into the red zone, battery, coolant warming up) so
// the screen can be checked without an ECU. Status bar shows "DEMO".
// Set to 0 for the real ECU.
#define DEMO_MODE 0

#define ECU_ADDRESS   0x10   // Motronic engine ECU - CONFIRMED working
#define COMM_BAUD     4800

#define BIT_MS        200    // 5-baud bit time
#define IDLE_BEFORE_MS 2000  // K-line must be idle high >= 2 s before the start bit

#define N_SYNC        5      // bytes to read after the 0x55 sync byte
#define KW_POS        1      // 0-based index of the keyword byte among those N_SYNC bytes
#define SYNC_TIMEOUT_MS 800  // wait per sync-byte attempt
#define SYNC_TRIES    3
#define BYTE_TIMEOUT_MS 150  // per-byte timeout while reading post-sync bytes
#define TURNAROUND_MS 8      // delay before the keyword reply (0x79) - accepted by the ECU

// Delay before EVERY byte we put on the K-line inside a block exchange: each
// inverted echo in readBlock() and each byte of sendBlock(). A 0 ms echo was
// rejected by the real ECU; 10, 15, 20, 25 and 30 ms all worked (sweep,
// 22 Sep 2026). 10 ms = the fastest tested value (more rpm updates per
// second); go back to 20 ms (the value used for the first full sessions) if
// the ECU starts rejecting echoes.
#define ECHO_DELAY_MS 10
unsigned long echoDelayMs = ECHO_DELAY_MS;
#define SELF_ECHO_TIMEOUT_MS 50 // our own byte loops back through the L9637 within ~1 byte time

#define INFO_BLOCKS   2      // number of ECU info blocks expected during init
#define MAX_BLOCK_LEN 64
#define BLOCK_SLACK   4      // safety cap above LEN while scanning for EOB
#define EOB           0x03
#define ECU_LEN_INCLUDES_EOB 1 // 1 = confirmed on this ECU (raw trace, 22 Sep 2026): LEN counts
                               // COUNTER+TYPE+DATA+EOB. 0 = LEN excludes the 0x03.
#define MAX_LEN_REPEATS 3      // how often the ECU may re-send a block's LEN byte because it
                               // didn't accept our echo (it always does this once for block 1)

#define RETRY_SETTLE_MS 1000 // idle time between the END of one attempt and the next

// ---------- STATE ----------
bool ecuConnected = false;
unsigned long lastAttempt = 0;
uint8_t msgCounter = 0; // counter of the last block on the bus (ECU's first block is 01)
int lastTx = -1; // last byte WE transmitted, for self-echo discard (matches Python's last_tx)
unsigned long selfEchoErrors = 0; // bytes whose loopback was missing or wrong

// ---------- DASHBOARD (TFT, landscape 320 x 240) ----------
// The screen is a fixed dashboard; the detailed log goes to Serial only.
//
//   0..24    status bar: title + connection status
//   left     RPM arc gauge (0-8000, red zone from 6500) with the value inside
//   right    2 x 2 grid: BATTERY | COOLANT over AIR TEMP | AIR QTY
//   214..240 bottom line: ID numbers once connected, else the latest step
//
// Everything is drawn once in dashFrame(); updates only redraw what changed
// (the arc grows/shrinks by the difference, numbers overwrite themselves
// with text padding), so there is no flicker. All drawing happens outside
// the timing-critical K-line exchanges.
#define COL_BG      TFT_BLACK
#define COL_BAR     0x10A2      // status bar background
#define COL_FRAME   0x3186      // box outlines, gauge track
#define COL_LABEL   0x9CD3      // light grey labels
#define COL_REDZONE 0x6000      // dark red track in the red zone

#define G_CX   84               // gauge centre
#define G_CY   128
#define G_R    72               // outer radius
#define G_W    12               // ring thickness

// 2 x 2 value grid on the right: 0 = battery, 1 = coolant, 2 = air temp, 3 = air qty
#define PANEL_X  164
#define PANEL_Y  30
#define CELL_W   74
#define CELL_H   84
#define CELL_GAP 4
#define CELL_BATT 0
#define CELL_COOL 1
#define CELL_AIRT 2
#define CELL_AIRQ 3
#define G_A0   60               // TFT_eSPI arc angles: 0 = 6 o'clock, clockwise
#define G_A1   300              // 60..300 = 240 degree sweep over the top
#define RPM_MAX   8000
#define RPM_WARN  5000          // yellow from here
#define RPM_RED   6500          // red from here

bool dashReady = false;
int gaugeAngle = G_A0;          // current end of the coloured bar
uint16_t gaugeColor = TFT_GREEN;
String idHw, idSw, idPn;        // from the ECU's ID blocks

// ---- Shared state between the K-line code (loop, core 1) and the display
// task (core 0). ONLY the display task draws on the TFT after setup(); the
// K-line code just hands over values/texts, so SPI drawing can never delay a
// K-line echo. Numbers are single 32-bit words (atomic on the ESP32); the
// Strings are guarded by a mutex.
volatile int   shRpm  = -1;     // target rpm, -1 = no value
volatile float shBatt = -1;     // V, < 0 = no value
volatile float shCool = -1000;  // C, <= -999 = no value
volatile float shAirT = -1000;  // air temperature, C
volatile float shAirQ = -1;     // air quantity, raw ECU value
SemaphoreHandle_t dashMutex = NULL;
String   shStatus = "STARTING";
uint16_t shStatusCol = TFT_YELLOW;
bool     shStatusDirty = true;
String   shBottom = "";
uint16_t shBottomCol = COL_LABEL;
bool     shBottomDirty = false;

#define SPLASH_MS       5000    // how long the boot splash stays on screen
#define DASH_FRAME_MS   40      // ~25 frames per second
#define RPM_SMOOTHING   0.18f   // fraction of the remaining distance per frame:
                                // ~90% of a new value within ~12 frames (~0.5 s).
                                // Lower = smoother but lags more; 0.30 was the
                                // first setting and looked slightly too twitchy.

int rpmToAngle(int rpm) {
  if (rpm < 0) rpm = 0;
  if (rpm > RPM_MAX) rpm = RPM_MAX;
  return G_A0 + (long)rpm * (G_A1 - G_A0) / RPM_MAX;
}

uint16_t rpmColor(int rpm) {
  return rpm >= RPM_RED ? TFT_RED : rpm >= RPM_WARN ? TFT_YELLOW : TFT_GREEN;
}

// Draws the empty track between two angles (grey, dark red in the red zone).
void gaugeTrack(int a, int b) {
  int aRed = rpmToAngle(RPM_RED);
  if (a < aRed) tft.drawArc(G_CX, G_CY, G_R, G_R - G_W, a, min(b, aRed), COL_FRAME, COL_BG, true);
  if (b > aRed) tft.drawArc(G_CX, G_CY, G_R, G_R - G_W, max(a, aRed), b, COL_REDZONE, COL_BG, true);
}

void gaugeSet(int rpm) {
  int a = rpmToAngle(rpm);
  uint16_t col = rpmColor(rpm);
  if (col != gaugeColor) {                    // zone changed: repaint the whole bar
    if (a > G_A0) tft.drawArc(G_CX, G_CY, G_R, G_R - G_W, G_A0, a, col, COL_BG, true);
    if (a < G_A1) gaugeTrack(a, G_A1);
  } else if (a > gaugeAngle) {                // grow
    tft.drawArc(G_CX, G_CY, G_R, G_R - G_W, gaugeAngle, a, col, COL_BG, true);
  } else if (a < gaugeAngle) {                // shrink
    gaugeTrack(a, gaugeAngle);
  }
  gaugeAngle = a;
  gaugeColor = col;
}

void drawSplash() {
  tft.fillScreen(COL_BG);
#ifdef HAVE_LOGO
  // Images need the two bytes per pixel swapped; the library's own drawing
  // calls handle that internally, pushImage() does not.
  tft.setSwapBytes(true);
  tft.pushImage((320 - LOGO_BIG_SIZE) / 2, 2, LOGO_BIG_SIZE, LOGO_BIG_SIZE, alfaLogo120);
  tft.setSwapBytes(false);
#endif
  // Two short lines under the badge: car name, then credits.
  tft.setTextDatum(MC_DATUM);
  tft.setTextColor(TFT_WHITE, COL_BG);
  tft.drawString("ALFA 145 QV", 160, 214, 2);
  tft.setTextColor(COL_LABEL, COL_BG);
  tft.drawString("by Paul Velzeboer", 160, 230, 1);
}

int cellX(int i) { return PANEL_X + (i % 2) * (CELL_W + CELL_GAP); }
int cellY(int i) { return PANEL_Y + (i / 2) * (CELL_H + CELL_GAP); }

void drawText(const String &txt, int x, int y, uint8_t datum, int font, uint16_t fg,
              uint16_t bg, int padding) {
  tft.setTextDatum(datum);
  tft.setTextColor(fg, bg);
  tft.setTextPadding(padding);
  tft.drawString(txt, x, y, font);
  tft.setTextPadding(0);
}

// Static parts; called once from setup() before the display task starts.
void dashFrame() {
  tft.fillScreen(COL_BG);
  tft.fillRect(0, 0, 320, 24, COL_BAR);
#ifdef HAVE_LOGO
  tft.setSwapBytes(true);
  tft.pushImage(4, (24 - LOGO_SMALL_SIZE) / 2, LOGO_SMALL_SIZE, LOGO_SMALL_SIZE, alfaLogo18);
  tft.setSwapBytes(false);
  drawText("ALFA 145 QV", 8 + LOGO_SMALL_SIZE, 12, ML_DATUM, 2, TFT_WHITE, COL_BAR, 0);
#else
  drawText("ALFA 145 QV", 6, 12, ML_DATUM, 2, TFT_WHITE, COL_BAR, 0);
#endif

  // gauge: track, ticks every 1000 rpm, 0 and 8 under the ends
  gaugeTrack(G_A0, G_A1);
  gaugeAngle = G_A0;
  gaugeColor = TFT_GREEN;
  for (int k = 0; k <= 8; k++) {
    float a = (G_A0 + k * (G_A1 - G_A0) / 8) * DEG_TO_RAD;
    float sn = sin(a), cs = cos(a);
    int r1 = G_R - G_W - 3, r2 = r1 - (k % 2 ? 3 : 6);
    tft.drawLine(G_CX - r1 * sn, G_CY + r1 * cs, G_CX - r2 * sn, G_CY + r2 * cs,
                 k * 1000 >= RPM_RED ? TFT_RED : COL_LABEL);
  }
  drawText("0", G_CX - 56, G_CY + 48, MC_DATUM, 2, COL_LABEL, COL_BG, 0);
  drawText("8", G_CX + 56, G_CY + 48, MC_DATUM, 2, COL_LABEL, COL_BG, 0);
  drawText("rpm", G_CX, G_CY + 36, MC_DATUM, 2, COL_LABEL, COL_BG, 0);
  drawText("x1000", G_CX, G_CY + 62, MC_DATUM, 1, COL_LABEL, COL_BG, 0);

  // 2 x 2 value grid: title (left), unit (right), value in the middle.
  // Units live in the labels so the value line can stay as wide as possible.
  for (int i = 0; i < 4; i++) {
    int x = cellX(i), y = cellY(i);
    tft.drawRoundRect(x, y, CELL_W, CELL_H, 5, COL_FRAME);
    const char *title = i == CELL_BATT ? "BATTERY" : i == CELL_COOL ? "COOLANT" :
                        i == CELL_AIRT ? "AIR TEMP" : "AIR QTY";
    // Titles in the small font (font 1): font 2 was too wide for a 74 px cell,
    // so "AIR TEMP" + unit didn't line up with the others.
    drawText(title, x + 5, y + 10, ML_DATUM, 1, COL_LABEL, COL_BG, 0);
    // Unit on its own line under the title, centred over the value.
    int ux = x + CELL_W / 2;
    if (i == CELL_BATT) {
      drawText("V", ux, y + 22, MC_DATUM, 1, COL_LABEL, COL_BG, 0);
    } else if (i == CELL_AIRQ) {
      // kg/h as requested; the ECU's scaling for this value is not verified yet
      drawText("kg/h", ux, y + 22, MC_DATUM, 1, COL_LABEL, COL_BG, 0);
    } else {                                   // degree sign: built-in fonts have none
      tft.drawCircle(ux - 2, y + 19, 2, COL_LABEL);
      drawText("C", ux + 5, y + 22, MC_DATUM, 1, COL_LABEL, COL_BG, 0);
    }
  }

  dashReady = true;
}

// ---- Called from the K-line code: only store, never draw.
void dashStatus(const String &txt, uint16_t color) {
  if (!dashMutex) return;
  xSemaphoreTake(dashMutex, portMAX_DELAY);
  shStatus = txt; shStatusCol = color; shStatusDirty = true;
  xSemaphoreGive(dashMutex);
}

void dashBottom(const String &txt, uint16_t color) {
  if (!dashMutex) return;
  xSemaphoreTake(dashMutex, portMAX_DELAY);
  shBottom = txt; shBottomCol = color; shBottomDirty = true;
  xSemaphoreGive(dashMutex);
}

void dashIds() {
  dashBottom("HW " + idHw + "  SW " + idSw + "  PN " + idPn, COL_LABEL);
}

// battV < 0, rpm < 0, coolantC/airT <= -999, airQ < 0 mean "no value" (--).
void dashValues(float battV, int rpm, float coolantC, float airT, float airQ) {
  shBatt = battV;
  shRpm = rpm;
  shCool = coolantC;
  shAirT = airT;
  shAirQ = airQ;
}

void drawCell(int i, const String &txt, uint16_t color) {
  drawText(txt, cellX(i) + CELL_W / 2, cellY(i) + 58, MC_DATUM, 4, color, COL_BG, CELL_W - 8);
}

// ---- Display task (core 0): the only code that draws after setup().
// The rpm gauge and number glide towards the latest reading every frame, so
// the needle moves smoothly although new values arrive only ~3-4x/s.
void dashTask(void *param) {
  float shownRpm = 0;
  int drawnRpm = -2;            // -2 = nothing drawn yet, -1 = "--" drawn
  float drawnBatt = -2, drawnCool = -2, drawnAirT = -2, drawnAirQ = -2;
  for (;;) {
    // status bar and bottom line (copied under the mutex, drawn outside it)
    String st, bt;
    uint16_t sc = 0, bc = 0;
    bool sd = false, bd = false;
    xSemaphoreTake(dashMutex, portMAX_DELAY);
    if (shStatusDirty) { st = shStatus; sc = shStatusCol; sd = true; shStatusDirty = false; }
    if (shBottomDirty) { bt = shBottom; bc = shBottomCol; bd = true; shBottomDirty = false; }
    xSemaphoreGive(dashMutex);
    if (sd) {
      tft.fillRect(170, 0, 150, 24, COL_BAR);
      int w = tft.textWidth(st, 2);
      tft.fillCircle(314 - w - 10, 12, 5, sc);
      drawText(st, 314, 12, MR_DATUM, 2, sc, COL_BAR, 0);
    }
    if (bd) drawText(bt, 6, 227, ML_DATUM, 2, bc, COL_BG, 308);

    // rpm: ease towards the target, redraw only when the shown value changes
    int target = shRpm;
    if (target < 0) {
      shownRpm = 0;
      if (drawnRpm != -1) {
        gaugeSet(0);
        drawText("--", G_CX, G_CY + 8, MC_DATUM, 6, COL_LABEL, COL_BG, tft.textWidth("8888", 6));
        drawnRpm = -1;
      }
    } else {
      shownRpm += (target - shownRpm) * RPM_SMOOTHING;
      if (fabsf(target - shownRpm) < 5) shownRpm = target;
      int r = (int)(shownRpm + 0.5f);
      if (r != drawnRpm) {
        gaugeSet(r);
        int r10 = (r + 5) / 10 * 10;          // number in 10 rpm steps: calmer to read
        drawText(String(r10), G_CX, G_CY + 8, MC_DATUM, 6, TFT_WHITE, COL_BG, tft.textWidth("8888", 6));
        drawnRpm = r;
      }
    }

    float bv = shBatt;
    if (bv != drawnBatt) {
      uint16_t col = bv < 0 ? COL_LABEL : bv < 11.8 ? TFT_RED : bv < 12.2 ? TFT_YELLOW :
                     bv <= 14.8 ? TFT_GREEN : TFT_RED;
      drawCell(CELL_BATT, bv < 0 ? String("--") : String(bv, 2), col);
      drawnBatt = bv;
    }
    float cv = shCool;
    if (cv != drawnCool) {
      uint16_t col = cv <= -999 ? COL_LABEL : cv < 60 ? TFT_SKYBLUE : cv <= 105 ? TFT_GREEN : TFT_RED;
      drawCell(CELL_COOL, cv <= -999 ? String("--") : String(cv, 1), col);
      drawnCool = cv;
    }
    float av = shAirT;
    if (av != drawnAirT) {
      uint16_t col = av <= -999 ? COL_LABEL : av < 5 ? TFT_SKYBLUE : av <= 60 ? TFT_GREEN : TFT_RED;
      drawCell(CELL_AIRT, av <= -999 ? String("--") : String(av, 1), col);
      drawnAirT = av;
    }
    float qv = shAirQ;
    if (qv != drawnAirQ) {
      drawCell(CELL_AIRQ, qv < 0 ? String("--") : String((int)(qv + 0.5f)), qv < 0 ? COL_LABEL : TFT_WHITE);
      drawnAirQ = qv;
    }

    vTaskDelay(pdMS_TO_TICKS(DASH_FRAME_MS));
  }
}

// Log line: always to Serial; while not connected, also the dashboard's
// bottom line (the ID numbers live there once connected).
void logLine(const String &msg, uint16_t color = TFT_GREEN) {
  Serial.println(msg);
  if (!ecuConnected) dashBottom(msg, color);
}

// ECU ID blocks carry their number as reversed ASCII: "8744021620" -> "0261204478".
String reversedId(const uint8_t *blk, int len) {
  String out;
  for (int i = len - 2; i >= 2; i--) {       // data = blk[2 .. len-2], blk[len-1] = 0x03
    if (blk[i] >= '0' && blk[i] <= '9') out += (char)blk[i];
  }
  return out;
}

// Serial-only, fast - used inside timing-critical sections so we never stall
// the lock-step echo with slow SPI/TFT writes.
void dbg(const String &msg) {
  Serial.println(msg);
}

String hexs(const uint8_t *buf, int len) {
  String s;
  for (int i = 0; i < len; i++) {
    if (buf[i] < 0x10) s += "0";
    s += String(buf[i], HEX);
    if (i != len - 1) s += " ";
  }
  return s;
}

// ---------- RAW K-LINE TRACE ----------
// Every byte on the wire, timestamped (us since the end of the wakeup stop
// bit), like the Python tool's --raw-trace. Dumped over Serial whenever a
// block fails, so you can see exactly which byte the ECU stopped after and
// how fast each echo went out. Recording is cheap; printing only happens
// after a failure, outside the timing-critical part.
//   TX = byte we sent   SE = its self-echo (loopback)   RX = byte from the ECU
//   -- = read timeout (nothing arrived)
#define TRACE_MAX 200
uint32_t traceT[TRACE_MAX];
char     traceTag[TRACE_MAX];
uint8_t  traceByte[TRACE_MAX];
int      traceN = 0;
uint32_t traceT0 = 0;
char     readTag = 'R';          // tag for the next kReadByte(): 'R' ECU byte, 'S' self-echo

void traceReset() {
  traceN = 0;
  traceT0 = micros();
}

void traceAdd(char tag, uint8_t b) {
  if (traceN < TRACE_MAX) {
    traceT[traceN] = micros() - traceT0;
    traceTag[traceN] = tag;
    traceByte[traceN] = b;
    traceN++;
  }
}
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
void loop() {
#if DEMO_MODE
  demoStep();
  return;
#endif

  if (!ecuConnected) {
    if (millis() - lastAttempt > RETRY_SETTLE_MS) {
      msgCounter = 0;
      lastTx = -1;
      dashStatus("CONNECTING", TFT_YELLOW);
      bool synced = wakeupAndSync(ECU_ADDRESS);
      if (synced) {
        logLine("Echo delay " + String(echoDelayMs) + " ms", TFT_CYAN);
        ecuConnected = runInit();
        if (ecuConnected) {
          logLine("== HANDSHAKE COMPLETE (echo delay " + String(echoDelayMs) + " ms) ==", TFT_GREEN);
          dashStatus("CONNECTED", TFT_GREEN);
          dashIds();
        } else {
          dashStatus("HANDSHAKE FAIL", TFT_ORANGE);
        }
      } else {
        dashStatus("NO ECU", TFT_RED);
      }
      // Settle is measured from the END of the attempt; the wakeup itself
      // adds another IDLE_BEFORE_MS of idle-high before the start bit.
      lastAttempt = millis();
    }
    return;
  }

  if (!pollAndDisplayParams()) {
    logLine("Session lost - self-echo errors so far: " + String(selfEchoErrors) +
            " - reconnecting", TFT_RED);
    ecuConnected = false;
    dashStatus("RECONNECTING", TFT_ORANGE);
    lastRpm = -1; lastBatt = -1; lastCool = -1000;
    dashValues(-1, -1, -1000, -1000, -1);
    lastAttempt = millis();
    return;
  }
}

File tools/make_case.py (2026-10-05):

#!/usr/bin/env python3
"""
make_case.py - generates a two-part 3D-printable case for the ESP32-2432S028
"Cheap Yellow Display" + MikroE ISO 9141 Click, as STL files.

    python3 tools/make_case.py            # writes hardware/*.stl

ALL DIMENSIONS ARE NOMINAL (datasheet / published values), NOT measured on
your boards - check the fit before printing the whole thing (see
hardware/README.md) and change the numbers in the PARAMETERS block below.

Layout (looking down on the open bottom shell):

    +-------------------------------------------+
    |  o                     o   | screw term. ->|   <- cut-out in the wall
    |     [    CYD board    ]    |  [ Click ]    |
    |  o                     o   |               |
    +---------[USB]-----------------------------+   <- cut-out in the wall

The bottom shell holds both boards on posts; the lid has a window for the
display and drops over the shell with a lip (friction fit, no screws).
Geometry is built only from boxes and tubes, so no CAD kernel is needed: walls
with openings are emitted as several boxes around the opening.
"""
import argparse
import math
import struct
import zipfile

# Badge outlines traced from an image by tools/trace_badge.py, if they exist.
# Without them the clover below is drawn from curves instead.
try:
    from badge_data import BADGE_BACK, BADGE_FRONT
except ImportError:                                 # pragma: no cover
    BADGE_BACK = BADGE_FRONT = None

# ---------------------------------------------------------------------------
# PARAMETERS - all in mm. Measure your boards and correct these.
# ---------------------------------------------------------------------------
# Board outline and hole pattern from the manufacturer drawing:
# https://mischianti.org/wp-content/uploads/2025/04/ESP32-2432S028-Cheap-Yellow-Display-Dimensions.jpg.webp
# 4.0 + 78.0 + 4.0 = 86.0 long, 4.0 + 42.0 + 4.0 = 50.0 wide, corners R1.6.
CYD_W, CYD_D, CYD_T = 86.0, 50.0, 1.6      # board outline and PCB thickness
CYD_HOLE_DIA = 3.0                          # mounting hole diameter (not dimensioned: verify)
CYD_HOLE_INSET_X, CYD_HOLE_INSET_Y = 4.0, 4.0   # hole centre from board edge -> 78 x 42 pattern
CYD_SCREEN_W, CYD_SCREEN_D = 57.6, 43.2    # active display area (2.8", 320x240)
CYD_SCREEN_OFF_X, CYD_SCREEN_OFF_Y = 0.0, 0.0   # screen centre vs board centre
CYD_STACK_H = 4.0                           # glass/bezel height above the PCB

# ISO 9141 Click, from iso_9141_click_v101.dxf (outline layer and pad positions):
# outline 25.40 x 28.57 mm; two 8-pin headers 22.86 mm apart, i.e. 1.27 mm from
# the long edges, pins from 3.81 to 21.59 mm along the board; screw terminals
# near the other end. Mounted PINS UP, so the terminals hang underneath.
CLICK_W, CLICK_D, CLICK_T = 25.40, 28.57, 1.6   # X = across the headers, Y = along them
CLICK_PIN_INSET = 1.27                      # header row from the long edge
CLICK_PIN_Y0, CLICK_PIN_Y1 = 3.81, 21.59    # first and last pin along the board
# Terminal height below the board: estimated from the fit-check print (the
# board sat 3.0 mm up and needed "2-4 mm more"). MEASURE IT: it is the only
# number that sets how high the board sits.
CLICK_TERM_STACK = 7.0                      # terminals stand this far below the board
CLICK_TERM_CLEAR = 1.5                      # air under the terminals
CLICK_TERM_X0, CLICK_TERM_X1 = 6.0, 17.0    # terminal bodies occupy this x band
CLICK_BOARD_Z = CLICK_TERM_STACK + CLICK_TERM_CLEAR   # floor to the underside of the PCB
CLICK_POCKET_DEPTH = 3.0                    # back edge slides this far into the pocket
CLICK_RAIL_T = 2.0                          # pocket / guide wall thickness
CLICK_LIP_T = 1.5                           # lip over the board in the pocket
CLICK_LEDGE_LEN = 5.0                       # support ledges at the terminal end
CLICK_NUB_H = 0.5                           # snap nub on the ledges (0 = rely on the lid)
CLICK_WIRE_W = 22.0                         # opening in the wall for the terminal wires
CLICK_PIN_H = 8.0                           # how far the header pins stick up above the
                                            # Click PCB - MEASURE THIS. Add more if plugs
                                            # stay on the pins with the lid closed.
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

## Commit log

2026-09-22 Initial commit: KWP71 reader for Bosch M2.10.4 on ESP32 CYD + ISO 9141 Click
    - firmware: KWP71 handshake, block protocol with raw trace, polling and a
    TFT dashboard (rpm gauge, battery, coolant, ECU IDs) with demo mode;
    K-line loopback test sketch
    - tools: PC KWP71 tool for a KKL cable, M2.10.4 simulator, 5-baud wakeup
    checker for sigrok captures
    - docs: bring-up plan, wiring, measured protocol facts, troubleshooting
    [golden.csv]
2026-09-22 Dashboard rework, faster rpm polling, LEN fix in the PC tools
    Firmware:
    - TFT dashboard: 2 x 2 value grid (battery, coolant, air temp, air quantity),
    smaller rpm gauge, boot splash with the car badge and credits
    - display drawn by its own task on core 0 at ~25 fps with eased rpm, so screen
    updates can never delay a K-line echo
    - polling reworked: one exchange per pass, rpm in 8 of 10 (~3-4 values/s),
    echo delay 10 ms
    - CYD panel fixes: backlight on, colour inversion off, BGR order, byte swap
    around pushImage
    - optional logo header via __has_include; demo mode simulates all values
    Tools:
    - kwp71_m2_10_4.py and m2104_sim.py: LEN counts the 0x03, repeated LEN byte
    echoed but not stor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
    [kwp71_m2104_esp32.ino, kwp71_m2_10_4.py, m2104_sim.py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]
2026-10-05 added 3d case
    Printable case for the CYD + ISO 9141 Click, generated by tools/make_case.py:
    shell with posts for the CYD (hole pattern from the manufacturer drawing) and
    a slide-in holder for the Click (geometry from iso_9141_click_v101.dxf, since
    its mounting holes are unusable and the headers sit 1.27 mm from the edges),
    plus a lid with the display window and the quadrifoglio inlaid in its top
    layers. case_lid.3mf carries the lid and badge as one object in three parts
    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
    [case_bottom.stl, case_clickfit.stl, case_fitcheck.stl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]
2026-10-12 Add air temp and air quantity, fix the rpm and battery scales
    A discovery sweep of all 16 ADC channels across five engine states named
    the two channels the dashboard was missing, and caught two formulas that
    were wrong:
    - air temp is ADC 05 (raw 197 reads 13 C against a 14 C ambient) and air
    quantity is ADC 04 (6 engine off, ~41 idle, ~70 at 3000 rpm). Both are
    polled now, so all five dashboard values come from the car.
    - rpm: the two reply bytes are the same speed at two resolutions, low x 10
    up to 2550 rpm and high x 40 past it. A held 3000 rpm averaged 74.6 on
    the high byte. The old 0.2 x high x low gave 328 at idle.
    - battery: 0.073 V/step, fitted to raw 164 at rest and 198 char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
2026-10-12 L-shaped rpm bar, cell symbols and dashboard animation
    Replaces the circular dial with an L that runs along the bottom edge and up
    the right edge, wrapping the value cells. The corner is fixed at half of
    RPM_MAX, so the bottom leg carries 0-4000 and the side leg 4000-8000; the two
    legs therefore read at different resolutions (13 vs 25 rpm per pixel), which
    is why both carry labels in thousands.
    Symbols: a tachometer dial beside the rpm number, and a battery, thermometer
    in water, thermometer in air and three airflow arrows in the four cells. Each
    takes its own value's colour, so every cell doubles as a warning lamp. The
    titles shorten to BATT / COOL / AIR T / AIR Q to leave room for the ico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
2026-10-12 Add rpm history trace, shift LED, auto-dimming and a 7-segment number
    Fills the one piece of dead space on the screen and puts two bits of onboard
    CYD hardware to use.
    - rpm history: a filled trace in a framed box under the number, one sample per
    250 ms across 118 columns, so about 30 s scrolling leftwards, each column in
    its own sample's zone colour with a dim line marking the red zone behind it.
    236 bytes of RAM. It replaces the "x1000 on the bar" hint, which was
    redundant once both legs of the bar carried labels in thousands.
    - onboard LED: the CYD's red LED (GPIO 4, active low) flashes with the shift
    light, so the warning carries in peripheral vision. Note the printed lid has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
2026-10-13 Touch-switched diagnostics page, fault reading, bar graduations, thicker lid
    Screen
    - a tap anywhere switches between the dashboard and a new diagnostics page.
    Switching needs only press detection, never a coordinate, so it reads PENIRQ
    on GPIO 36 with one digitalRead: no second SPI bus (the XPT2046 is on its own
    here and User_Setup.h has no TOUCH_ settings), no library, nothing to
    calibrate. GPIO 36 is input-only with no pull-up and sits next to the display
    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
2026-10-13 Fill the diagnostics page in demo mode, and move the session extremes
    Demo mode only drove page 1, so the new diagnostics page was empty without an
    ECU and there was no way to judge it.
    - all 12 ADC channels are now generated, with every formula fitted to the
    discovery runs rather than invented: at idle the demo reads throttle 27, air
    quantity 39, channel 06 75 and lambda 156, and at 3000 rpm 38 / 71 / 51 / 158,
    which lands inside all eight measured ranges. Lambda is the one deliberate
    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
2026-10-14 SD drive logging with fault codes, screw ears, and fix the lid fouling the boards
    Logging
    - every drive is written to the CYD's micro-SD slot as the next free
    /logNNNN.csv: time_s,link,rpm,batt_v,coolant_c,airtemp_c,airqty_raw,dtc, one
    row per second. Verified by reading the file back off the card, not just by
    compiling: 58 rows with the expected values and columns.
    - it runs in its own task on core 0, and that is not optional. A row normally
    takes 6-7 ms to write and flush, but a measured spike of 186 ms turned up
    where the card updated its allocation table; in the K-line loop that would
    have overrun the echo window by an order of magnitude and dropped the session.
    - every row i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
2026-10-14 Add a photo of the finished reader working in the car
    Installed on the car and running a real session, not demo mode: connected,
    1280 rpm on a cold fast idle, 14.53 V charging, coolant and intake air both at
    20 C, and the ECU's own part numbers along the bottom.
    The photo is downscaled from 3024x4032 / 2.7 MB to 1200x1600 / 439 KB, since a
    git repository keeps the original for good and nothing in the documentation
    needs that resolution.
    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
